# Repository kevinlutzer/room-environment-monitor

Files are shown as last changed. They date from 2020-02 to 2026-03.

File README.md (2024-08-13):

# Overview 

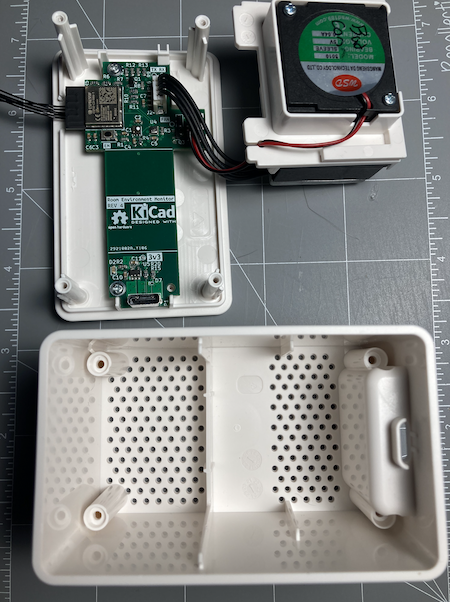
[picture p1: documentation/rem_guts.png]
REM Guts


The Room Environment Monitor (REM) project was something that I started back in 2017. I wanted a small IoT device that could tell me if there was a concerning amount of volatile organic compounds (VOCs) and CO2 in my workshop. I built the first version based on a Raspberry Pi Zero, CCS811 air quality monitor, and a BME280 humidity and temperature sensor.

I went through multiple iterations of the project with the overall objective to reduce cost while increasing the precision of the measurements being made. At that time, the CCS811 sensor cost about 40 dollars alone, which brought the V1 bill of materials (BOM) cost to about 70 CAD. Fast forward to 2023, Ikea released their [Vindriktning](https://www.ikea.com/ca/en/p/vindriktning-air-quality-sensor-60515911/) air quality monitor which uses a [PM1006K](https://en.gassensor.com.cn/Product_files/Specifications/LED%20Particle%20Sensor%20PM1006K%20Specification.pdf) sensor to measure 2.5um matter in the air. I designed my latest version of the Room Environment Monitor to replace the controller inside and make use of the device's case.

# Data Collection

The REM collects data from the following sensors:
1. [BME280](https://www.bosch-sensortec.com/products/environmental-sensors/humidity-sensors-bme280/) - Temperature, Humidity, Pressure
1. [SGP40-2.5k](https://sensirion.com/products/catalog/SGP40) - VOCs, C02  
1. [PM1006K](https://en.gassensor.com.cn/ParticulateMatterSensor/info_itemid_105.html) - particulate matter in the air (2.5ug/m^3, 1.0ug/m^3, 10ug/m^3)

This data is then pushed to a MQTT broker via the MQTT networking protocal. The broker then broadcasts the data to any subscribers. I use [n8n](https://n8n.io/) which is a workflow automation tool to subscribe to the REM data stream. n8n ensures that each piece of data in this stream is inserted as a new row in to a Postgres database. Bellow is a sequence diagram that shows how the data flows and is collected. 

<!-- https://sequencediagram.org/
title Room Environment Monitor Data Collection 

REM->MQTT Broker:publish data over tcp/ip using MQTT
MQTT Broker->n8n:broad cast data over tcp/ip using MQTT 
n8n->Postgres: insert new row  -->

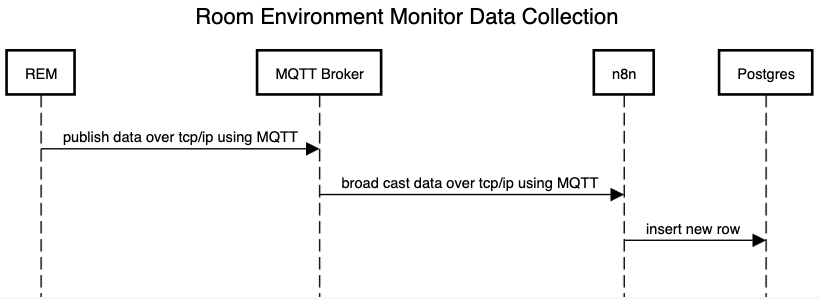
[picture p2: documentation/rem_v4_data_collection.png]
Data Collection Sequence Diagram


<!-- # Data Visualization -->

I use Grafana, a free an open source tool to visualize the collected data in my Postgres database. Here is a screenshot of the dashboard that I have created to visualize the data.

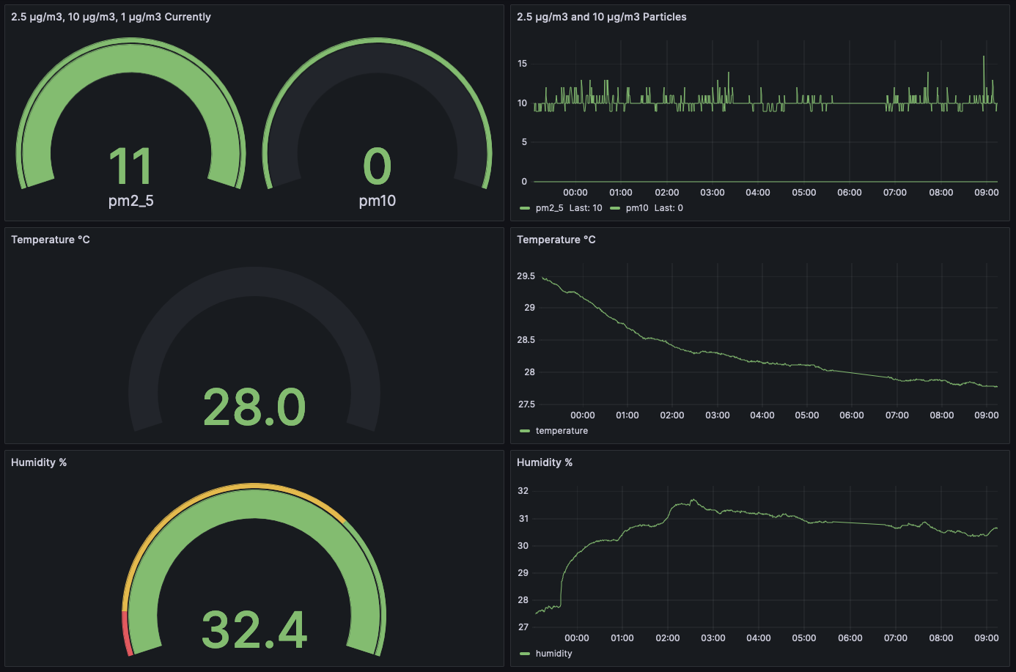
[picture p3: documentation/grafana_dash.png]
Data Visualization


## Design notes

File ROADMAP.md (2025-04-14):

# Roadmap 🗺️

1. Add the ability for the sample rate to be dynamically updated over mqtt.
1. Add TLS and user/password auth support.
1. Integrate the security chip. Right now the firmware does not use the onboard security chip (TPM) for hashing, password storage, etc.

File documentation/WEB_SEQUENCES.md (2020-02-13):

title Data Collection and Transmission Sequence (Raspberry PI)

Raspberry Pi->+Air Sensor: get air quality data
Air Sensor-->-Raspberry Pi: data
Raspberry Pi->+Temperature Sensor: get temperature and humidity
Temperature Sensor-->-Raspberry Pi: data
Raspberry Pi->+Google IOT Core: publishes data as message
Google IOT Core-->-Raspberry Pi: reciept for recieved message

title Data Store and Processing Sequence (Google Cloud Platform)

Google IOT Core->Google Pubsub: publish data from raspberry pi
Google Pubsub-->-Google IOT Core: success
Google Pubsub->+Google Function: recieve pub/sub message with data
Google Function->+Firestore: writes data to database
Firestore-->-Google Function: success
Google Function-->-Google Pubsub: sucess

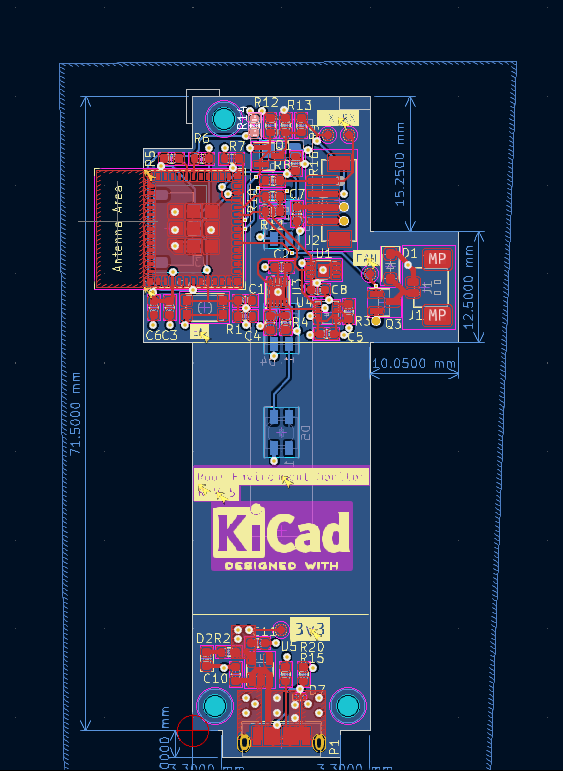
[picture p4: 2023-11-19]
documentation/v5-pcb 2/board_layout.png

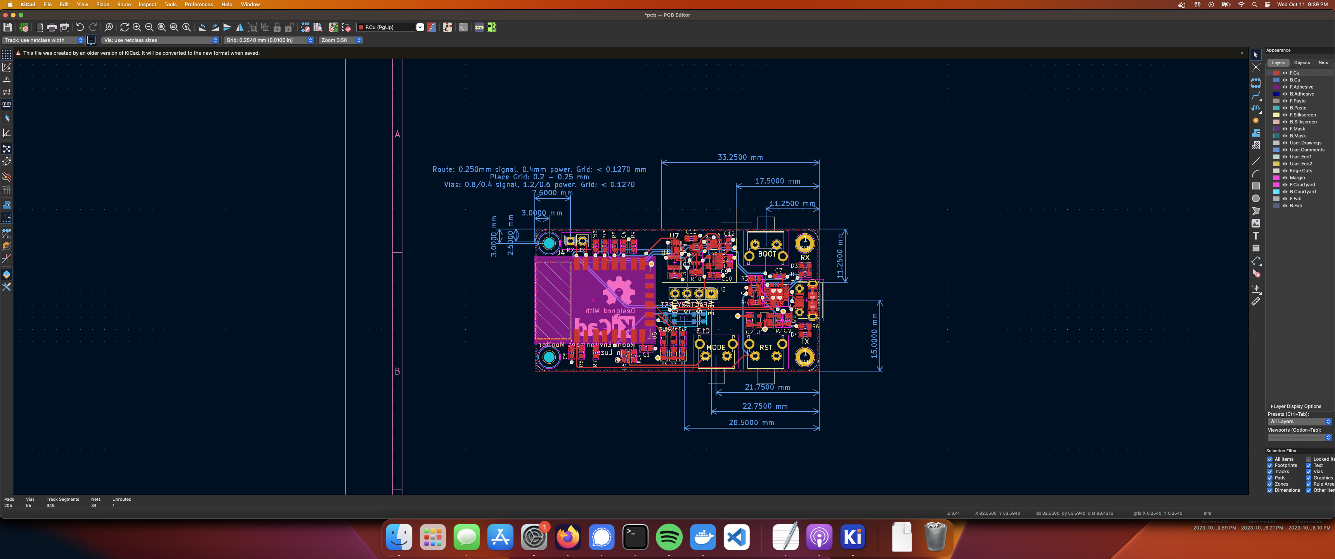
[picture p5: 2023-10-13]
documentation/v2/pcb.png

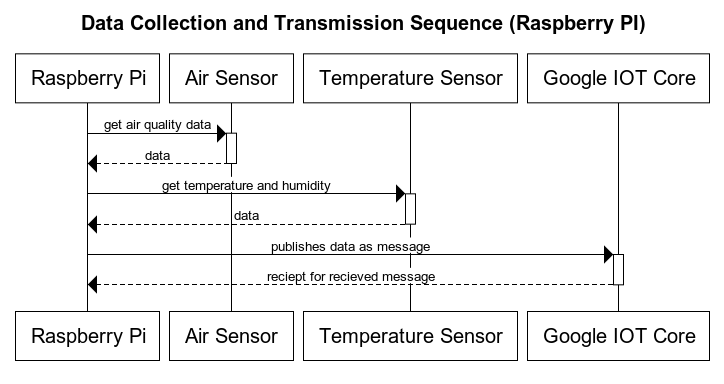
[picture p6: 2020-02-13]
documentation/data_collection_raspberry_pi_transmission_sequence_diagram.png

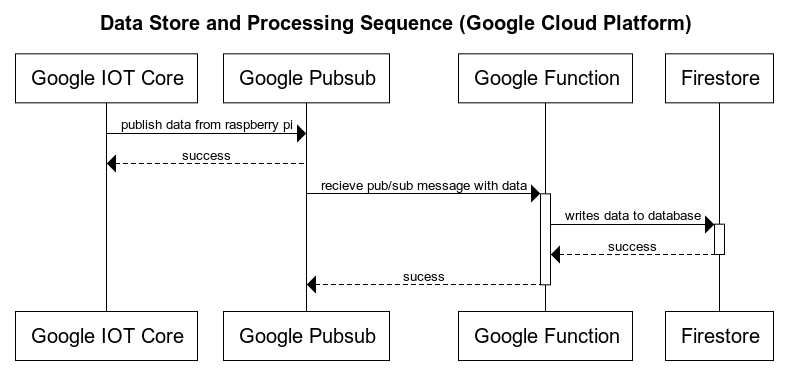
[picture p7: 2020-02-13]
documentation/data_store_and_processing_sequence_google_cloud_platform.png

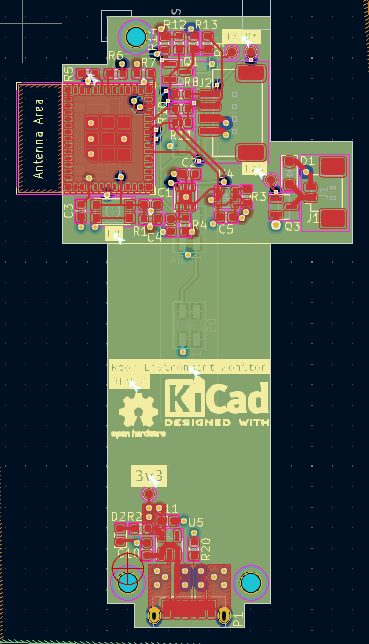
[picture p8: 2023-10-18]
documentation/v4-pcb/board_layout.png

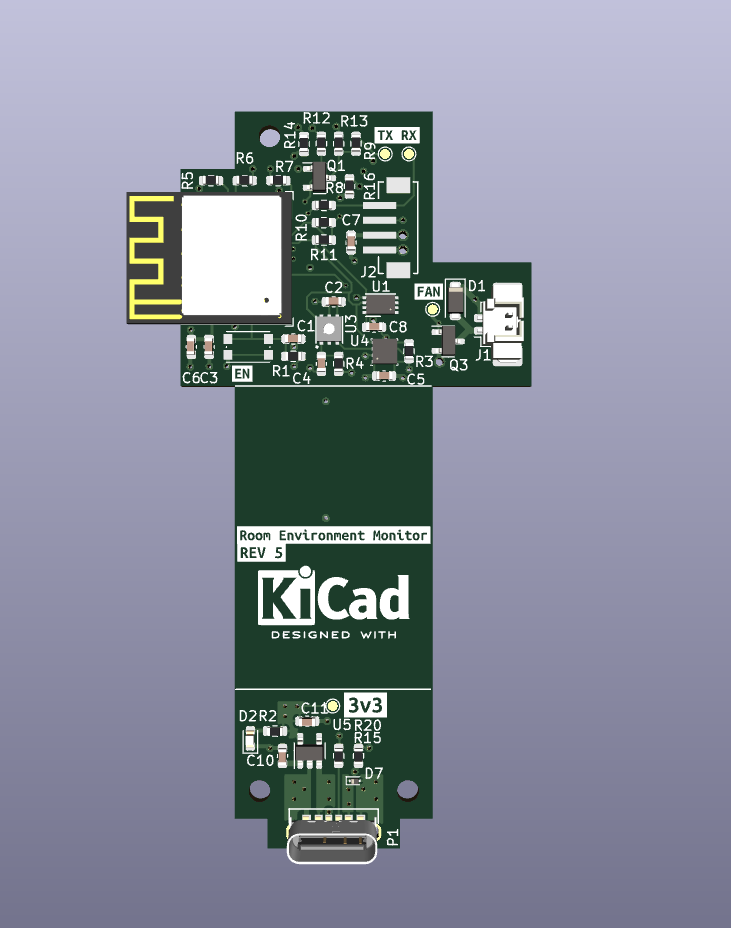
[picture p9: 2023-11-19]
documentation/v5-pcb 2/3d.png

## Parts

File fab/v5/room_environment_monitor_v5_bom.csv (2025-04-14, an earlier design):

Reference | Value | Datasheet | Footprint | Qty | DNP
C1,C2,C3,C4,C5,C8 | 0u1 | ~ | Capacitor_SMD:C_0603_1608Metric | 6 | C1590
C6,C7,C10,C11 | 1u | -- mixed values -- | Capacitor_SMD:C_0603_1608Metric | 4 | C1592
D1 | CDBMS160 | https://wmsc.DNP.com/wmsc/upload/file/pdf/v2/DNP/2312271638_Comchip-CDBMS160-HF_C7100383.pdf | Diode_SMD:D_SOD-123F | 1 | C7100383
D2 | LED | ~ | LED_SMD:LED_0603_1608Metric | 1 | C1590
D7 | ESD9X3 | https://www.onsemi.com/pdf/datasheet/esd9x3.3st5g-d.pdf | Diode_SMD:D_SOD-923 | 1 | C130456
J1 | Conn_01x02_Pin | ~ | Connector_Molex:Molex_PicoBlade_53398-0271_1x02-1MP_P1.25mm_Vertical | 1 | C122410
J2 | Conn_01x04_Pin | ~ | Kevin_Lutzer_Lbr:CONN_B4B-ZR-SM4-TF_JST | 1 | C265083
Q1,Q3 | BSS138 | -- mixed values -- | Package_TO_SOT_SMD:SOT-23 | 2 | C52895
R1,R3,R7,R12,R13,R16 | 10k | ~ | Resistor_SMD:R_0603_1608Metric | 6 | C15401
R2 | 220 | ~ | Resistor_SMD:R_0603_1608Metric | 1 | C1226
R4 | 4.7 | ~ | Resistor_SMD:R_0603_1608Metric | 1 | C23162
R5,R6,R8,R9 | 0 | ~ | Resistor_SMD:R_0603_1608Metric | 4 | C15402
R10,R11 | 2k2 | ~ | Resistor_SMD:R_0603_1608Metric | 2 | C4190
R15,R20 | 5.1k | ~ | Resistor_SMD:R_0603_1608Metric | 2 | C14677
SW1 | SW_SPST | ~ | Button_Switch_SMD:SW_Push_1P1T_NO_CK_KMR2 | 1 | C72443
U2 | ESP32-C3-MINI-1 | https://www.espressif.com/sites/default/files/documentation/esp32-c3-mini-1_datasheet_en.pdf | PCM_Espressif:ESP32-C3-MINI-1 | 1 | C2838502
U3 | SGP30-2.5K | https://mm.digikey.com/Volume0/opasdata/d220001/medias/docus/2578/SGP30%20Datasheet.pdf | Kevin_Lutzer_Lbr:SGP30-2.5K_SEN | 1 | C2874215
U4 | BME280 | https://www.bosch-sensortec.com/media/boschsensortec/downloads/datasheets/bst-bme280-ds002.pdf | Package_LGA:Bosch_LGA-8_2.5x2.5mm_P0.65mm_ClockwisePinNumbering | 1 | C92489
U5 | AP2112K-3.3 | https://www.diodes.com/assets/Datasheets/AP2112.pdf | Package_TO_SOT_SMD:SOT-23-5 | 1 | C51118

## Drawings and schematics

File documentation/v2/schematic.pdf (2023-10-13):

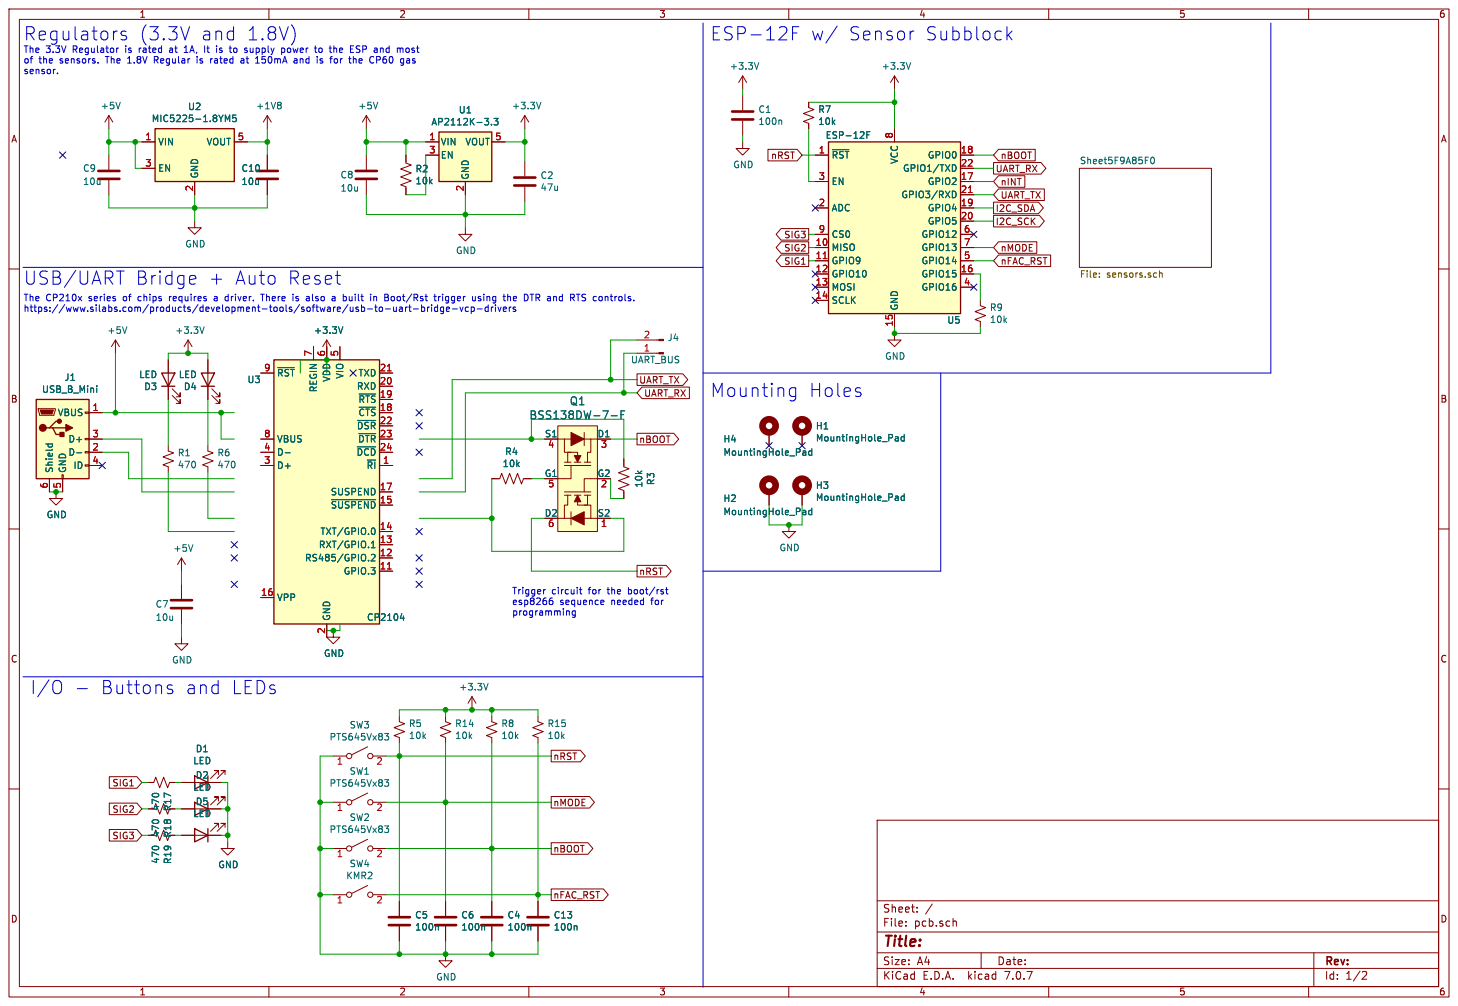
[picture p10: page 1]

USB/UART Bridge + Auto Reset

ID 4 GND 5 Shield 6 GND

Id: 1/2 Title: File: pcb.sch Sheet: /

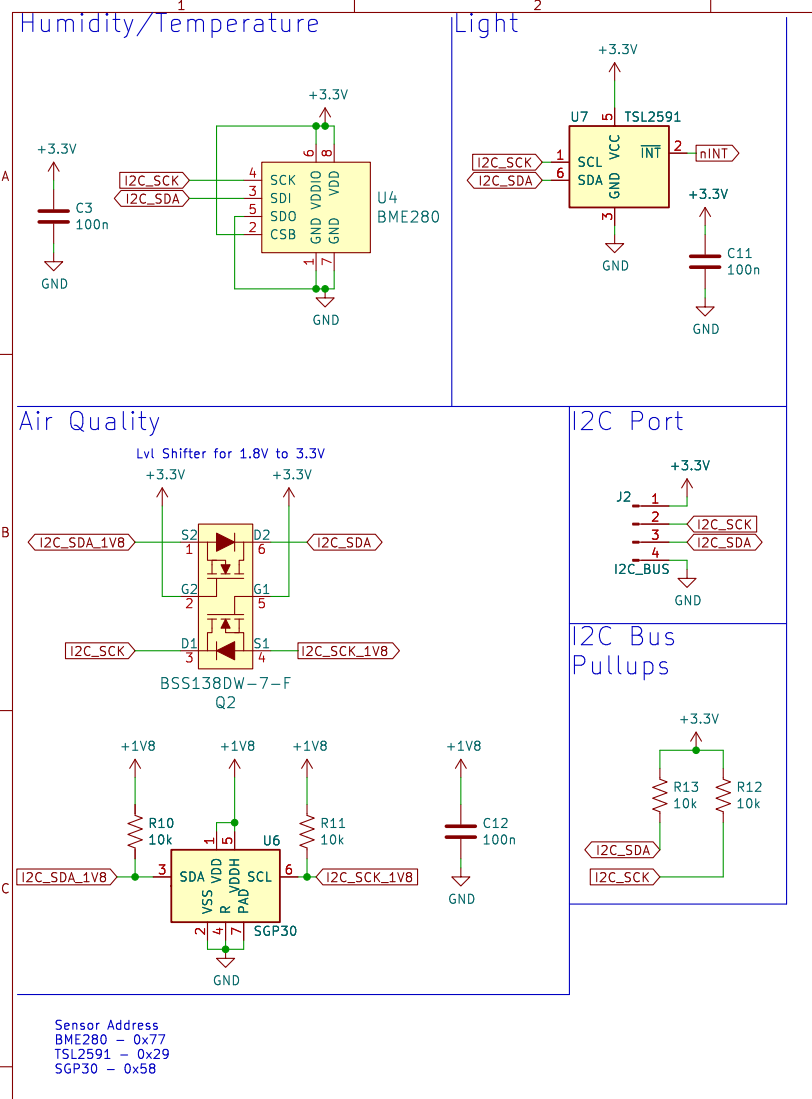
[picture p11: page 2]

I2C Port Sensor Address BME280 - 0x77 TSL2591 - 0x29 SGP30 - 0x58 Humidity/Temperature

1 CSB 2 SDI 3 SCK 4 SDO 5 VDDIO

File: sensors.sch Sheet: /Sheet5F9A85F0/
Id: 2/2 Title: Sensors

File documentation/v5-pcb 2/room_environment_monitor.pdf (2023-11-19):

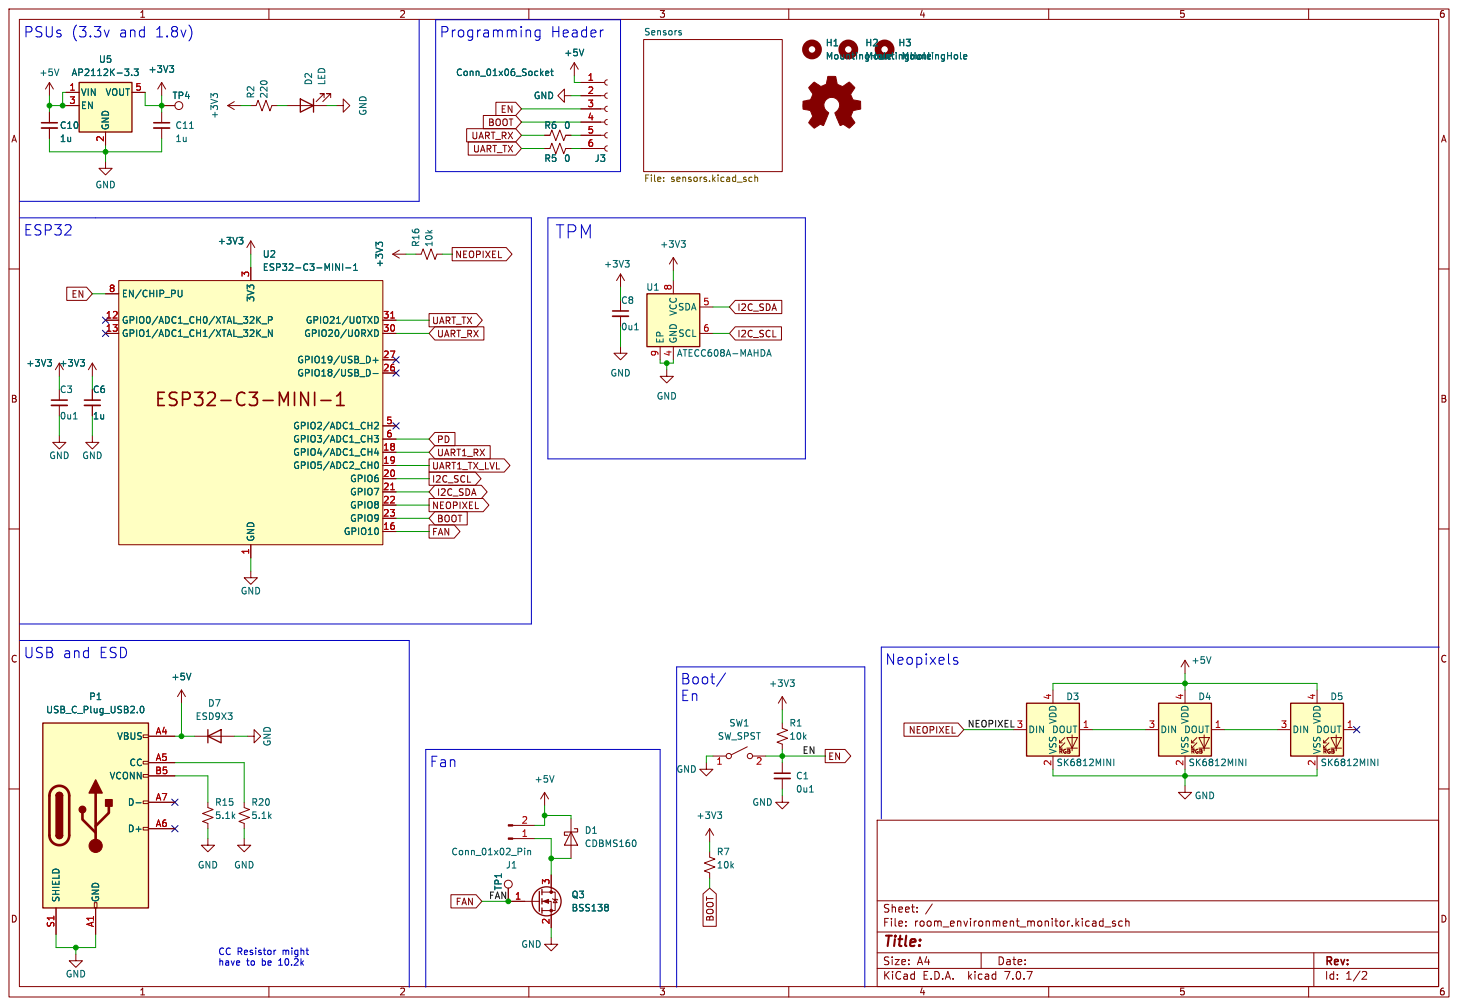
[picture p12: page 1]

2 EN 3 VOUT 5 U5 AP2112K-3.3 GND A1 VBUS A4 CC A5 D+ A6 D- A7 VCONN B5 SHIELD S1 P1 USB_C_Plug_USB2.0

2 EN 3 VOUT 5 +3V3 TP4 U2ESP32-C3-MINI-1 GND

Neopixels USB and ESD

Id: 1/2 Title: File: room_environment_monitor.kicad_sch Sheet: /

CC Resistor might have to be 10.2k

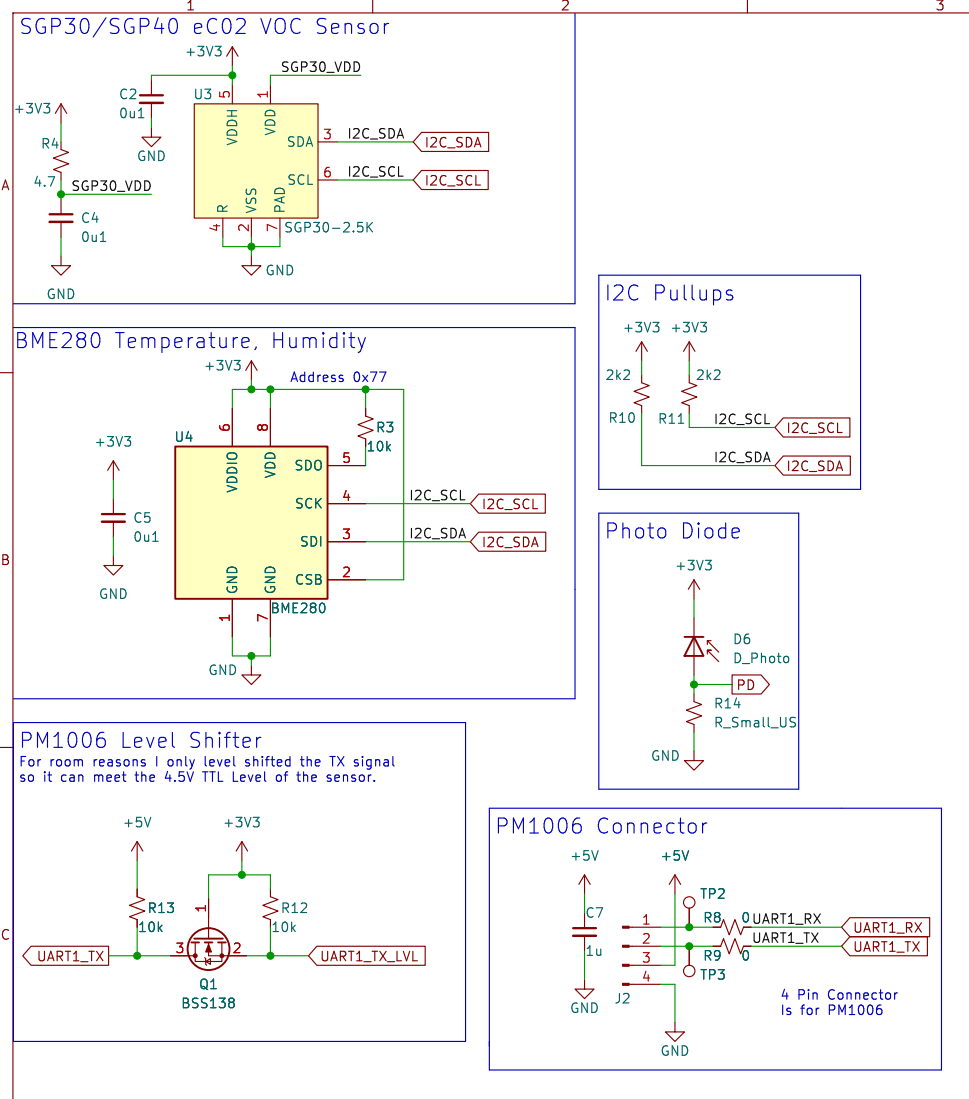
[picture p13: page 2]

1 CSB 2 SDI 3 SCK 4 SDO 5 VDDIO

Id: 2/2 Title: File: sensors.kicad_sch Sheet: /Sensors/

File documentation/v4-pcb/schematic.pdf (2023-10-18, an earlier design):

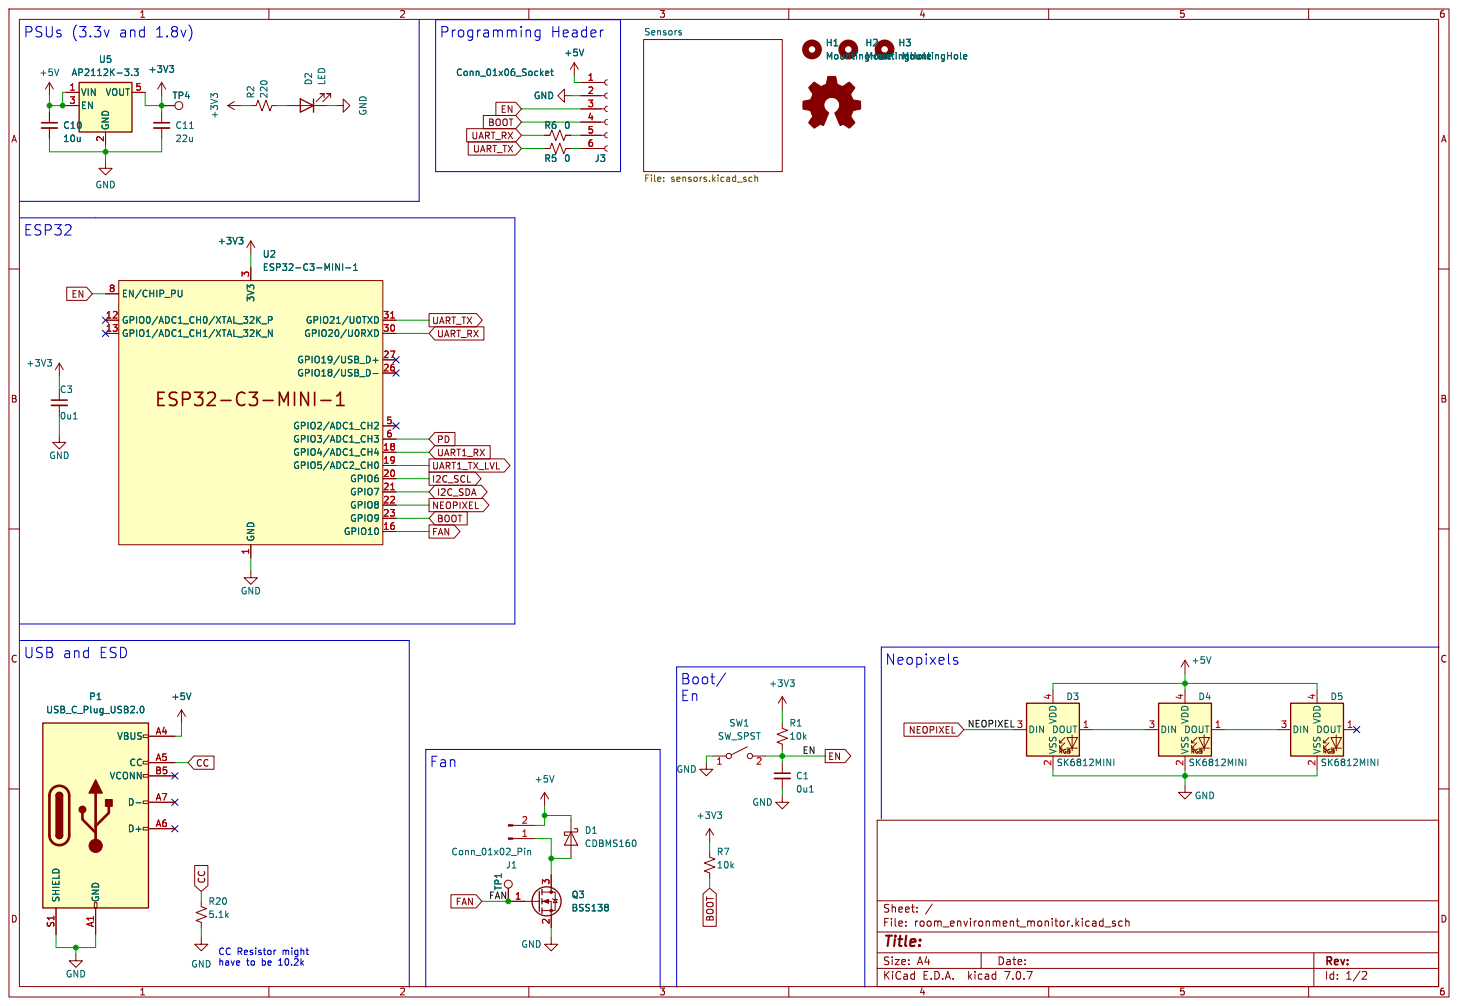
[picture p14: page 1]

2 3TP1 P1 +5V USB_C_Plug_USB2.0 GND A1 VBUS A4 CC A5 D+ A6 D- A7 VCONN B5 SHIELD S1 U2ESP32-C3-MINI-1 GND

CC Resistor might have to be 10.2k USB and ESD

2 3 Q3 BSS138 GND A1 VBUS A4 CC A5 D+ A6 D- A7 VCONN B5 SHIELD S1 P1 USB_C_Plug_USB2.0 GND

Id: 1/2 Title: File: room_environment_monitor.kicad_sch Sheet: /

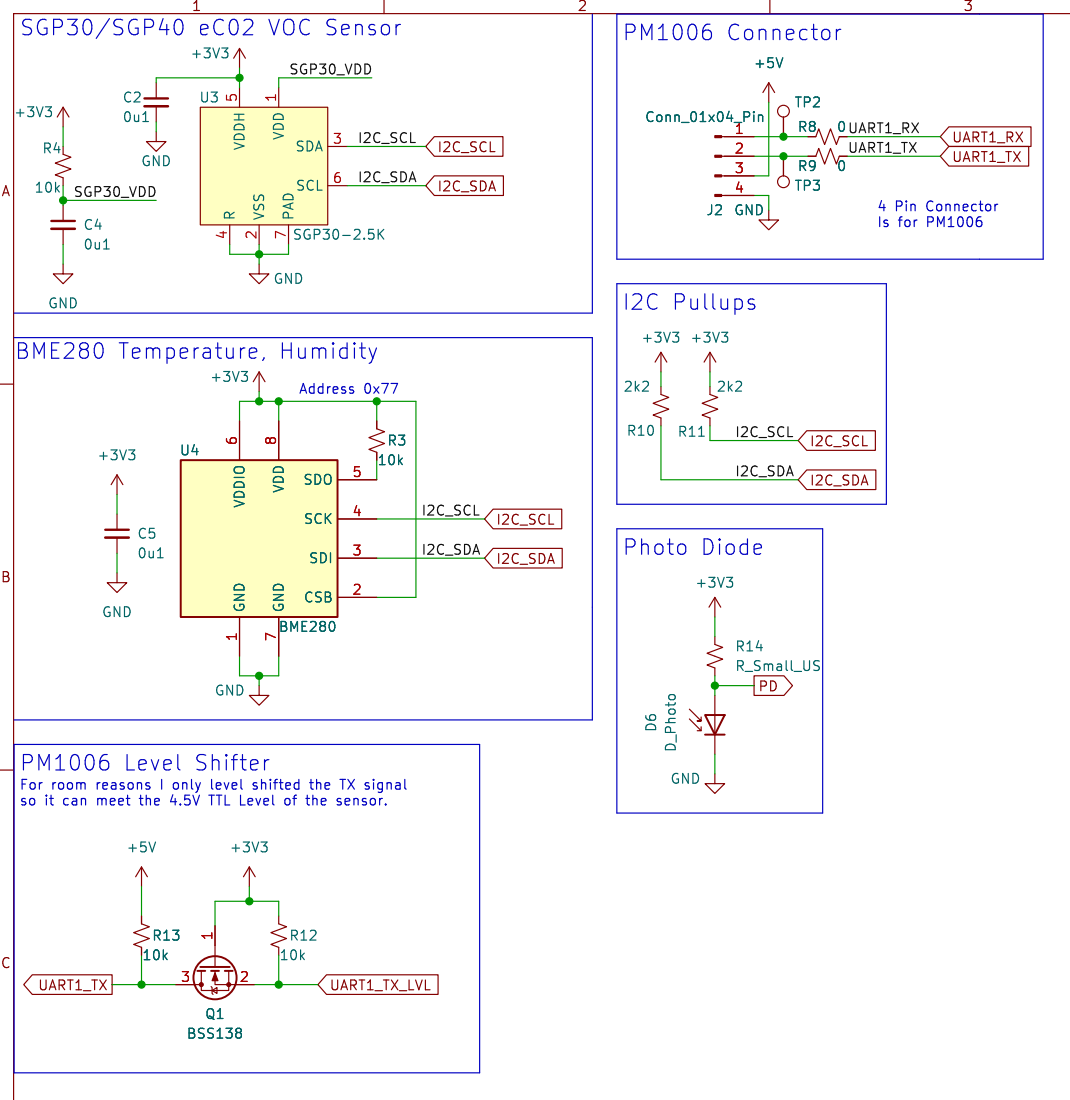
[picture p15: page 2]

1 CSB 2 SDI 3 SCK 4 SDO 5 VDDIO

PM1006 Level Shifter
For room reasons I only level shifted the TX signal so it can meet the 4.5V TTL Level of the sensor.

Id: 2/2 Title: File: sensors.kicad_sch Sheet: /Sensors/

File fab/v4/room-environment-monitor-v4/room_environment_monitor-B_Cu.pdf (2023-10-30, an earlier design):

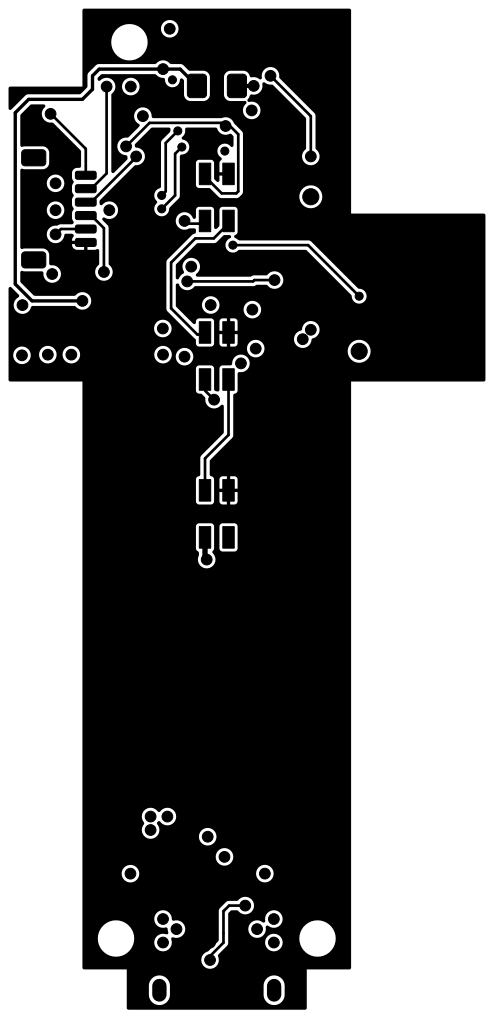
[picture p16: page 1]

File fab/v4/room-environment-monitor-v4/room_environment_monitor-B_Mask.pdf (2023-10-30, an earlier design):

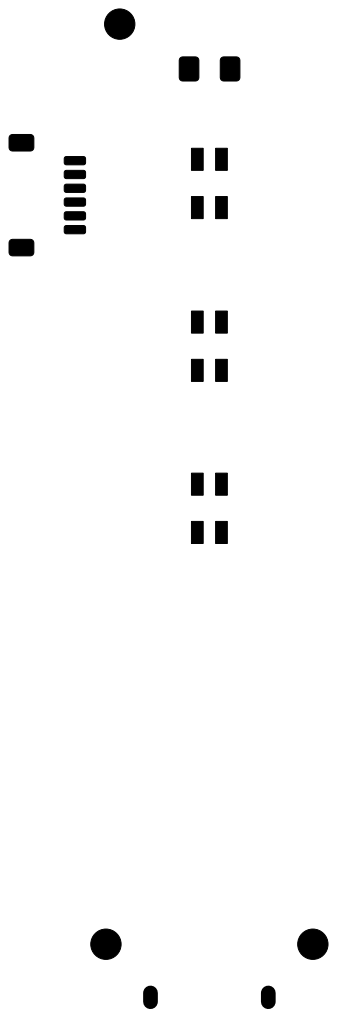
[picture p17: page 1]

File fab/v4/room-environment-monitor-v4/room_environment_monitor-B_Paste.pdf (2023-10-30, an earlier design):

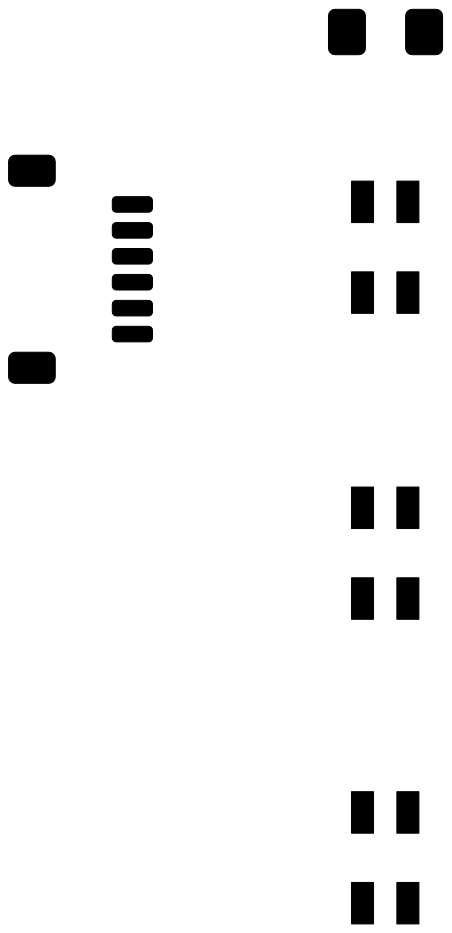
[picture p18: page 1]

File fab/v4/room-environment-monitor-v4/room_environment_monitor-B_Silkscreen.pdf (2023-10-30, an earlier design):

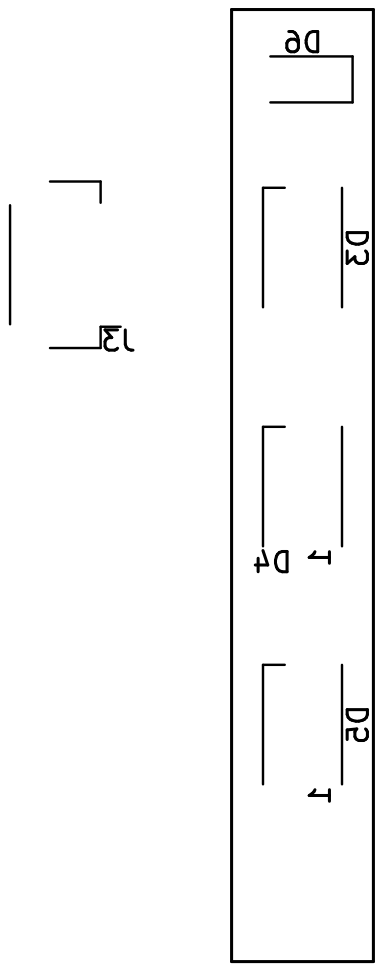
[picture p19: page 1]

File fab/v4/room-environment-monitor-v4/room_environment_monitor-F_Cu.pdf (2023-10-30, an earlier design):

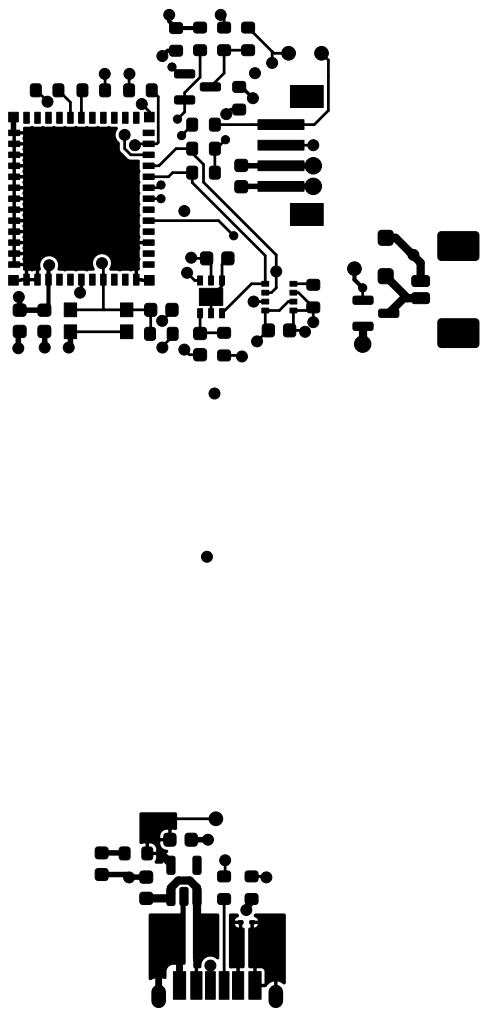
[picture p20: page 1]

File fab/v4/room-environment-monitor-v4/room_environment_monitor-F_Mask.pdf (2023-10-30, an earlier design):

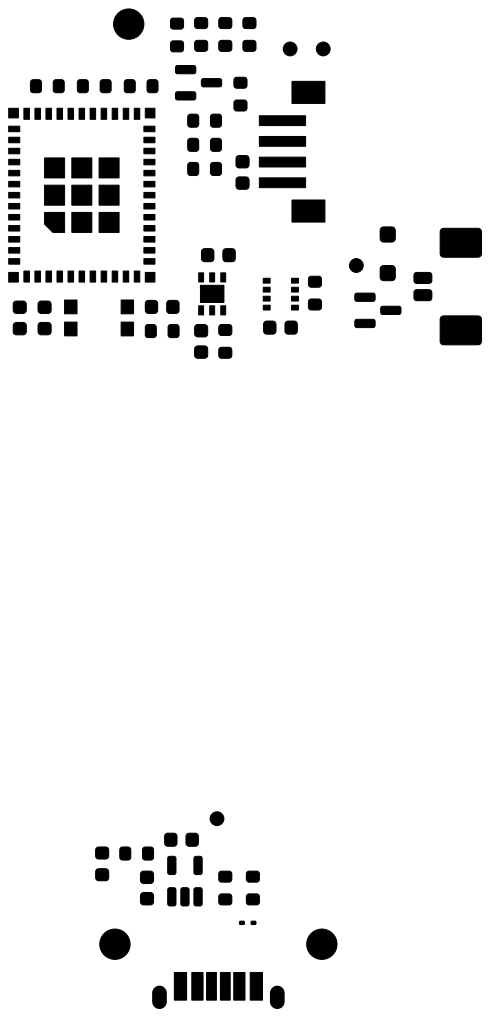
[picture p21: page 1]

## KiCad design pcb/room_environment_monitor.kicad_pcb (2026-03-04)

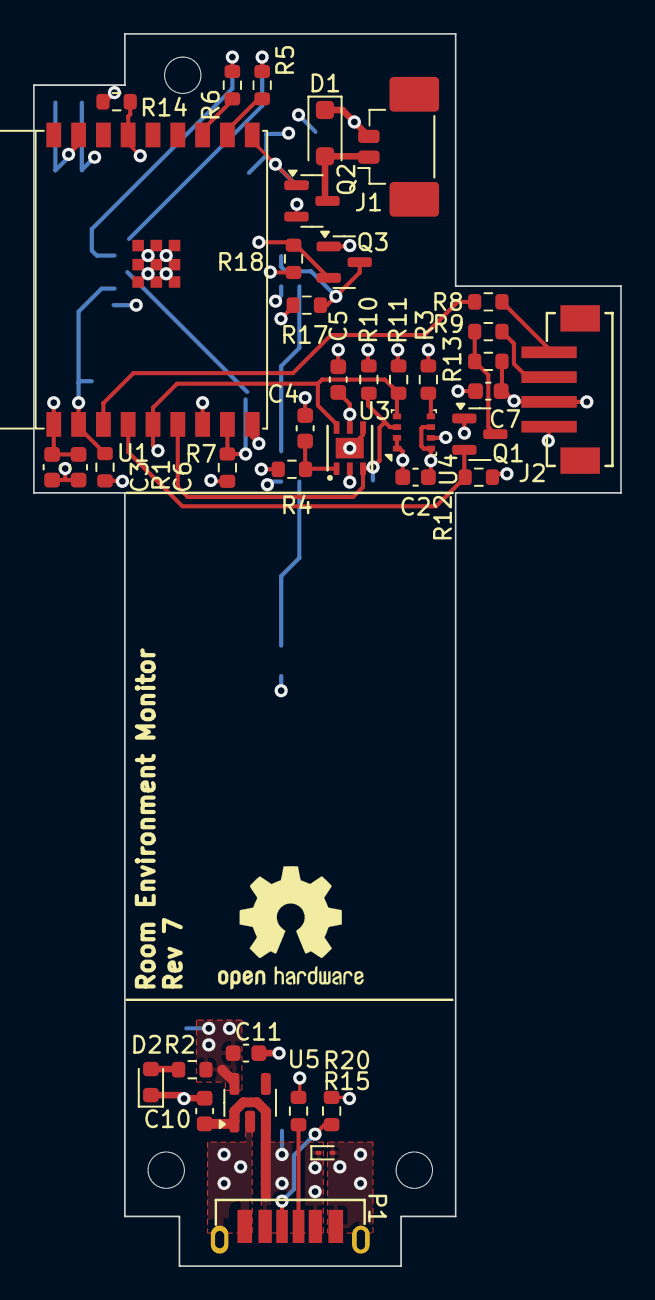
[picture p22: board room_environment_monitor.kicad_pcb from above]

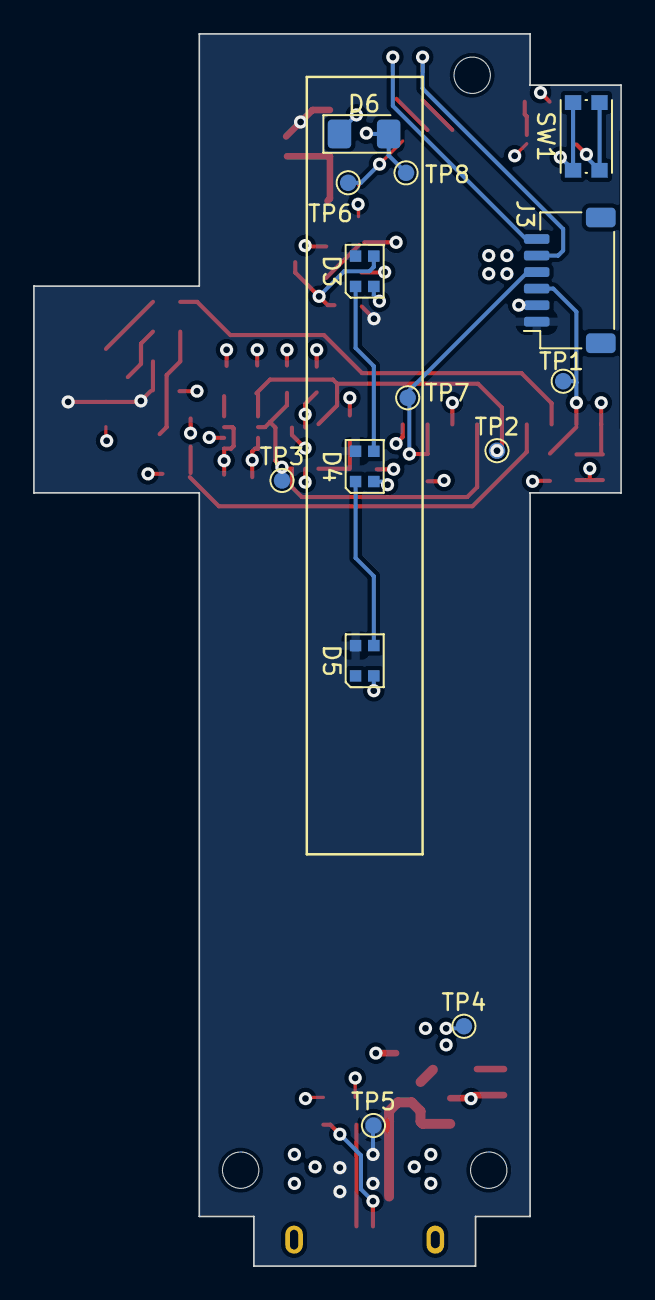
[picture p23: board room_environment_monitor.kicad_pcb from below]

Board: 4 copper layers, 35.5 x 74.5 mm, 56 parts (14 on the bottom side), 29 nets.

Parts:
C2, C3, C4, C5: 0u1; C_0603_1608Metric
C6, C7, C10, C11: 1u; C_0603_1608Metric
D1: CDBMS160; D_SOD-123F
D2: LED; LED_0603_1608Metric
D3, D4, D5: WS2812B-2020; LED_WS2812B-2020_PLCC4_2.0x2.0mm
D6: D_Photo; D_1206_3216Metric_Pad1.42x1.75mm_HandSolder
D7: ESD9X3; D_SOD-923
H1, H2, H3: MountingHole; MountingHole_2.2mm_M2_DIN965
J1: Conn_01x02_Pin; Molex_PicoBlade_53398-0271_1x02-1MP_P1.25mm_Vertical
J2: Conn_01x04_Pin; CONN_B4B-ZR-SM4-TF_JST
J3: Conn_01x06_Socket; JST_SH_SM06B-SRSS-TB_1x06-1MP_P1.00mm_Horizontal
P1: USB_C_Plug_USB2.0; CONN6_USB4130-GF-C_GCT
Q1, Q2, Q3: BSS138; SOT-23
R1, R3, R7, R12, R13, R17, R18: 10k; R_0603_1608Metric
R2: 220; R_0603_1608Metric
R4: 4.7; R_0603_1608Metric
R5, R6, R8, R9: 0; R_0603_1608Metric
R10, R11: 2k2; R_0603_1608Metric
R14: 10M; R_0603_1608Metric
R15, R20: 5.1k; R_0603_1608Metric
SW1: SW_SPST; SW_Push_1P1T_NO_CK_KMR2
TP1, TP2, TP3, TP4, TP5, TP6, TP7, TP8: TestPoint; TestPoint_Pad_D1.0mm
U1: ESP32-C3-WROOM-02
U3: SGP40; SGP30-2.5K_SEN-M
U4: BME280; Bosch_LGA-8_2.5x2.5mm_P0.65mm_ClockwisePinNumbering
U5: AP2112K-3.3; SOT-23-5

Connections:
+3V3: C2.1, C3.1, C5.1, C6.1, C11.1, D6.1 (K), Q1.1 (G), Q3.1 (G), R1.1, R2.1, R3.1, R4.1, R7.1, R10.2, R11.2, R12.1, R18.1, TP4.1, U1.1 (3V3), U3.5 (VDDH), U4.6 (VDDIO), U4.8 (VDD), U5.5 (VOUT)
+5V: C7.1, C10.1, D1.1 (K), D3.4 (VDD), D4.4 (VDD), D5.4 (VDD), D7.1 (K), J1.2, J2.3, J3.1, P1.A9 (VBUS), P1.B9 (VBUS), R13.1, R17.1, TP5.1, U5.1 (VIN), U5.3 (EN)
/NEOPIXEL_LVL: D3.3 (DIN), Q3.3 (D), R17.2
/Sensors/SGP30_VDD: C4.1, R4.2, U3.1 (VDD)
BOOT: J3.4, R7.2, TP7.1, U1.8 (GPIO9)
EN: J3.3, R1.2, TP1.1, U1.2 (EN/CHIP_PU)
FACT_REST: SW1.2 (B), U1.17 (GPIO1/ADC1_CH1/XTAL_32K_N)
FAN: Q2.1 (G), TP6.1, U1.10 (GPIO10)
GND: C2.2, C3.2, C4.2, C5.2, C6.2, C7.2, C10.2, C11.2, D2.1 (K), D3.2 (VSS), D4.2 (VSS), D5.2 (VSS), D7.2 (A), J2.4, J3.2, P1.A12 (GND), P1.B12 (GND), P1.S1 (SHIELD), Q2.2 (S), R14.1, R15.2, R20.2, SW1.1 (A), U1.9 (GND), U1.19 (GND), U3.2 (VSS), U3.4 (N/A), U3.7 (PAD), U4.1 (GND), U4.2 (CSB), U4.7 (GND), U5.2 (GND)
I2C_SCL: R11.1, TP2.1, U1.5 (GPIO6), U3.6 (SCL), U4.4 (SCK)
I2C_SDA: R10.1, TP3.1, U1.6 (GPIO7), U3.3 (SDA), U4.3 (SDI)
NEOPIXEL: Q3.2 (S), R18.2, U1.7 (GPIO8)
unnamed: D1.2 (A), J1.1, Q2.3 (D)
unnamed: D2.2 (A), R2.2
unnamed: D3.1 (DOUT), D4.3 (DIN)
unnamed: D4.1 (DOUT), D5.3 (DIN)
unnamed: J2.1, R8.1
unnamed: J2.2, R9.1
unnamed: J3.5, R6.2
unnamed: J3.6, R5.2
unnamed: P1.A5 (CC), R20.1
unnamed: P1.B5 (VCONN), R15.1
unnamed: R3.2, U4.5 (SDO)
PD: D6.2 (A), R14.2, TP8.1, U1.15 (GPIO3/ADC1_CH3)
UART1_RX: R8.2, U1.3 (GPIO4/ADC1_CH4)
UART1_TX: Q1.3 (D), R9.2, R13.2
UART1_TX_LVL: Q1.2 (S), R12.2, U1.4 (GPIO5/ADC2_CH0)
UART_RX: R6.1, U1.12 (GPIO21/U0TXD)
UART_TX: R5.1, U1.11 (GPIO20/U0RXD)

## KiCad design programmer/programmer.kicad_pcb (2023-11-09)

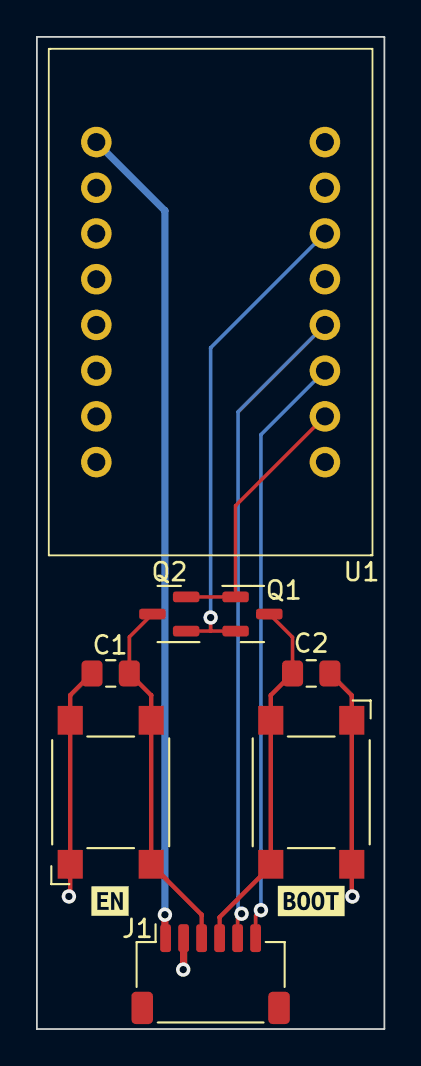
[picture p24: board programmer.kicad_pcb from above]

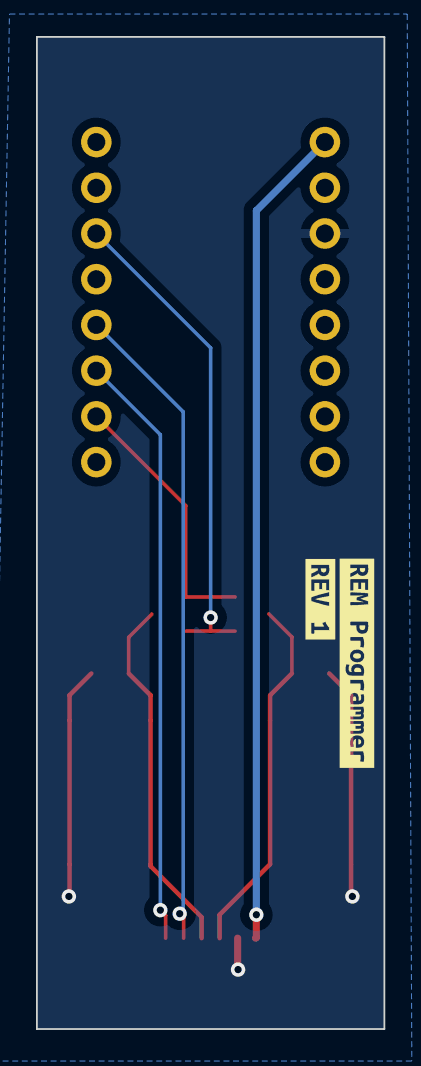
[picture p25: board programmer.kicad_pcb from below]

Board: 2 copper layers, 19.3 x 55.1 mm, 12 parts (2 on the bottom side), 8 nets.

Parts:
C1, C2: C; C_0805_2012Metric_Pad1.18x1.45mm_HandSolder
J1: Conn_01x06_Socket; JST_SH_SM06B-SRSS-TB_1x06-1MP_P1.00mm_Horizontal
Q1, Q2: BSS138; SOT-23
SW1, SW3: SW_Omron_B3FS; SW_SPST_Omron_B3FS-100xP
U1: Adafruit CP210XN Friend; Adafruit_CP210XN_Friend
kibuzzard-654D0F9E: G***; kibuzzard-654D0F9E
kibuzzard-654D0FC0: G***; kibuzzard-654D0FC0
kibuzzard-654D0FE8: G***; kibuzzard-654D0FE8
kibuzzard-654D1020: G***; kibuzzard-654D1020

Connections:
+5V: J1.1, U1.1 (VBUS)
BOOT: C2.1, J1.4, Q1.3 (D), SW3.2
DTR: Q1.2 (S), Q2.1 (G), U1.14 (DTR)
EN: C1.1, J1.3, Q2.3 (D), SW1.2
GND: C1.2, C2.2, J1.2, SW1.1, SW3.1, U1.3 (GND)
RTS: Q1.1 (G), Q2.2 (S), U1.10 (RTS)
UART_RX: J1.5, U1.12 (TXD)
UART_TX: J1.6, U1.11 (RXD)

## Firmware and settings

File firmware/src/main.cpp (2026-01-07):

#include "stdlib.h"

#include "Adafruit_BME280.h"
#include "Adafruit_NeoPixel.h"
#include "Adafruit_SGP40.h"
#include "EEPROM.h"
#include "PM1006K.h"
#include "PubSubClient.h"
#include "UUID.h"
#include "WiFi.h"
#include "Wire.h"

#include "mqtt_msg.hpp"
#include "pin_config.hpp"
#include "sensor_adapter.hpp"
#include "settings_manager.hpp"
#include "tasks.hpp"
#include "terminal.hpp"
#include "wifi_controller.hpp"

#define INIT_DEBUG false

#define PUBLISH_DATA_STACK 2048
#define PUBLISH_STATUS_STACK 4096
#define PUBLISH_TERMINAL_STACK 4096

#define SAMPLE_RATE 5000

// Statically create pointers to all of the providers.
// These instances should last the lifetime of the program
SensorAdapter *sensorAdapter;
SettingsManager *settingsManager;
PM1006K *pm1006k;
Adafruit_BME280 *bme280;
Adafruit_SGP40 *sgp40;
Adafruit_NeoPixel *neoPixel;
WiFiClient espClient;
Terminal *terminal;
PubSubClient *pubSubClient;
REMTaskProviders *providers;
LEDController *ledController;
UUID *uuidGenerator;

static BaseType_t prvRebootCommand(char *pcWriteBuffer, size_t xWriteBufferLen,
                                   const char *pcCommandString);

static const CLI_Command_Definition_t xRebootCommand = {
    "reboot", "\r\nreboot:\r\n this command reboots the esp32\r\n",
    prvRebootCommand, 0};

static BaseType_t prvUpdateSettingCommand(char *pcWriteBuffer,
                                          size_t xWriteBufferLen,
                                          const char *pcCommandString);

static const CLI_Command_Definition_t xUpdateSettingCommand = {
    "update-setting",
    "\r\nupdate-setting <NAME> <VALUE>:\r\n This command reboots the esp32. "
    "Valid settings include `ssid` and `password`\r\n",
    prvUpdateSettingCommand, 2};

static BaseType_t prvPrintSettingsCommand(char *pcWriteBuffer,
                                          size_t xWriteBufferLen,
                                          const char *pcCommandString);

static const CLI_Command_Definition_t xPrintSettingsCommand = {
    "print-settings",
    "\r\nprint-settings: \r\n This command will return a list of all of the "
    "settings and their values. \r\n",
    prvPrintSettingsCommand, 0};

static BaseType_t prvDebugCommand(char *pcWriteBuffer, size_t xWriteBufferLen,
                                  const char *pcCommandString);

static const CLI_Command_Definition_t xDebugCommand = {
    "debug", "\r\ndebug: \r\n This toggles the debug logging\r\n",
    prvDebugCommand, 0};

static BaseType_t prvWiFiStatusCommand(char *pcWriteBuffer,
                                       size_t xWriteBufferLen,
                                       const char *pcCommandString);

static const CLI_Command_Definition_t xWiFIStatusCommand = {
    "wifi-status",
    "\r\nwifi-status: \r\n Returns the wifi connected status\r\n",
    prvWiFiStatusCommand, 0};

static BaseType_t prvPrintSensorDataCommand(char *pcWriteBuffer,
                                            size_t xWriteBufferLen,
                                            const char *pcCommandString);

static const CLI_Command_Definition_t xPrintSensorDataCommand = {
    "print-sensor-data",
    "\r\nprint-sensor-data: \r\n Prints a snapshot of the sensor data.\r\n",
    prvPrintSensorDataCommand, 0};

/**
 * Setup the wifi connection and the NTP server. If the clock is not synced
 * with the NTP server, the function will return false
 */
void setupWiFi() {
  WiFiController *wifiController =
      new WiFiController(&WiFi, terminal, settingsManager);
  if (!wifiController->setupWiFi()) {
    terminal->debugln("Wifi Setup Failed");
  }

  wifiController->setupSNTP();
  if (!wifiController->verifyClockSync()) {
    terminal->debugln("Failed to sync the clock with the NTP server");
  }

  // Controller isn't needed again execpt for initial networking config
  delete wifiController;
}

/**
 * Setup the terminal and the terminal task that will handle the input and
 * output
 */
void setupTerminal() {

  Serial.begin(115200);
  terminal = new Terminal(INIT_DEBUG, &Serial);

  // Setup the terminal task that handles the input and output of the terminal
  xTaskCreate(TerminalTask, "Terminal Task", PUBLISH_TERMINAL_STACK, terminal,
              1, NULL);

  // Setup CLI Commands that can be run as soon as the terminal task is started
  FreeRTOS_CLIRegisterCommand(&xRebootCommand);
  FreeRTOS_CLIRegisterCommand(&xDebugCommand);
}

/**
 * Initializes the pubsub client which internally creates a MQTT connection to
 * the server. The server connected too is determeind by the mqtt server
 * setting.
 */
void setupPubSubClient() {
  pubSubClient = new PubSubClient(espClient);
  pubSubClient->setServer(settingsManager->getSetting(MQTT_SERVER_ID), 1883);
  pubSubClient->connect("arduinoClient");

  while (!pubSubClient->connected()) {
    terminal->debugln("Failed to connect to MQTT server, retrying...");
    pubSubClient->connect("arduinoClient");
    delay(1000);
  }
}

void setup() {

  Adafruit_NeoPixel NeoPixel(3, NEOPIXEL_PIN, NEO_GRB + NEO_KHZ800);
  NeoPixel.clear(); // set all pixel colors to 'off'. It only takes effect if
                    // pixels.show() is called

  // turn pixels to green one-by-one with delay between each pixel
  for (int pixel = 0; pixel < 3; pixel++) { // for each pixel
    NeoPixel.setPixelColor(
        pixel,
        NeoPixel.Color(0, 255,
                       0)); // it only takes effect if pixels.show() is called
    NeoPixel.show();        // update to the NeoPixel Led Strip

    delay(500); // 500ms pause between each pixel
  }

  // Turn on Fan
  pinMode(FAN, OUTPUT);
  digitalWrite(FAN, HIGH);

  setupTerminal();

  // Setup EEPROM
  int count = 0;
  while (count < 5 && !EEPROM.begin(EEPROM_SIZE)) {
    terminal->debugln("Failed to setup EEPROM, retrying...");
    count++;
    delay(1000);
  }

  // Setup settings manager and load settings from eeprom
  settingsManager = new SettingsManager(terminal, &EEPROM);
  if ((!settingsManager->loadSettings())) {
    terminal->debugln("Failed to load settings");
  }

  // Add tasks related to settings since settings manager is instantiated
  FreeRTOS_CLIRegisterCommand(&xUpdateSettingCommand);
  FreeRTOS_CLIRegisterCommand(&xPrintSettingsCommand);

  // Setup network utilities including the network connection,
  // sntp, and the mqtt client
  setupWiFi();
  setupPubSubClient();

  // Setup Controller and Controller Depedencies
  Serial1.begin(PM1006K::BAUD_RATE, SERIAL_8N1, PM1006K_RX_PIN, PM1006K_TX_PIN);
  pm1006k = new PM1006K(&Serial1);

  // Setup I2C
  Wire.begin(I2C_SDA, I2C_SCL);
  Wire.setClock(10000);

  // Setup BME280 Driver
  bme280 = new Adafruit_BME280();
  if (!bme280->begin(BME280_ADDRESS, &Wire)) {
    terminal->debugln("Failed to setup BME280");
  }

  // Setup the SGP40 Driver
  sgp40 = new Adafruit_SGP40();
  if (!sgp40->begin(&Wire)) {
    terminal->debugln("Failed to setup SGP40");
  }

  // Setup the neopixel controller and clear the pixels
  neoPixel =
      new Adafruit_NeoPixel(NUM_NEOPIXELS, NEOPIXEL_PIN, NEO_GRB + NEO_KHZ800);
  neoPixel->begin();
  neoPixel->clear();
  ledController = new LEDController(neoPixel, terminal);

  // Setup Controller
  sensorAdapter = new SensorAdapter(pm1006k, bme280, sgp40, terminal);

  // Create UUID Generator used for generating unique ids
  uuidGenerator = new UUID();
  uint32_t rn = esp_random();
  uuidGenerator->seed(rn);
  uuidGenerator->setRandomMode(); // This is important for the UUID to be unique
                                  // between reboots

  // Remainder of the commands that depend on providers instantiated above
  FreeRTOS_CLIRegisterCommand(&xWiFIStatusCommand);
  FreeRTOS_CLIRegisterCommand(&xPrintSensorDataCommand);

  // Setup the task providers and the task that publishes the messages
  providers = new REMTaskProviders(sensorAdapter, settingsManager, terminal,
                                   pubSubClient, uuidGenerator, ledController);

  xTaskCreate(PublishMQTTMsg, "Publish MQTT", PUBLISH_STATUS_STACK, providers,
              1, NULL);

  xTaskCreate(QueueDataTask, "Queue Data", PUBLISH_DATA_STACK, providers, 1,
              NULL);

  xTaskCreate(QueueStatusTask, "Status Data", PUBLISH_DATA_STACK, providers, 1,
              NULL);

  xTaskCreate(LEDUpdateTask, "LED Update Task", PUBLISH_DATA_STACK, providers,
              1, NULL);

#ifdef DEBUG_MEMORY_CHECK
  xTaskCreate(MemoryCheck, "Memory Check Task", PUBLISH_DATA_STACK, providers,
              1, NULL);

#endif

  terminal->debugln("Started tasks...");
}

// Main loop is uneeded because we are using freertos tasks to persist the
// application
void loop() { return; }

//
// Begin the CLI Command Definitions
//

BaseType_t prvRebootCommand(char *pcWriteBuffer, size_t xWriteBufferLen,
                            const char *pcCommandString) {
  ESP.restart();

  // Never reached because the esp32 reboots fully
  return pdTRUE;
}

BaseType_t prvUpdateSettingCommand(char *pcWriteBuffer, size_t xWriteBufferLen,
                                   const char *pcCommandString) {

  BaseType_t nameParamToStringLength, valueParamToStringLength;
  const char *nameParam =
      FreeRTOS_CLIGetParameter(pcCommandString, 1, &nameParamToStringLength);

  const char *valueParam =
      FreeRTOS_CLIGetParameter(pcCommandString, 2, &valueParamToStringLength);

  // Call the update function and validate the response note that if it is
  // false, it coul;d
  if (settingsManager->updateSetting(nameParam, valueParam,
                                     (int)valueParamToStringLength)) {
    snprintf(pcWriteBuffer, xWriteBufferLen, "Update setting successfully");
  } else {
    snprintf(pcWriteBuffer, xWriteBufferLen,
             "Failed to update setting check to make sure the setting name is "
             "valid and the length of the value is under %d characters",
             SETTING_LEN);
  }

  return pdFALSE;
}

BaseType_t prvDebugCommand(char *pcWriteBuffer, size_t xWriteBufferLen,
                           const char *pcCommandString) {

  bool debug_val = terminal->toggleDebug();
  snprintf(pcWriteBuffer, xWriteBufferLen, "Debug logging is now %s\r\n",
           debug_val ? "enabled" : "disabled");

  return pdFALSE;
}

BaseType_t prvPrintSettingsCommand(char *pcWriteBuffer, size_t xWriteBufferLen,
                                   const char *pcCommandString) {

  BaseType_t nameParamToStringLength, valueParamToStringLength;

  // If we get a false response from the print settings function, print an error
  // message It mostlikely is a memory allocation issue where xWriteBufferLen is
  // too small
  if (!settingsManager->printSettings(pcWriteBuffer, xWriteBufferLen)) {
    snprintf(pcWriteBuffer, xWriteBufferLen,
             "Failed to print the settings\r\n");
  }

  return pdFALSE;
}

BaseType_t prvWiFiStatusCommand(char *pcWriteBuffer, size_t xWriteBufferLen,
                                const char *pcCommandString) {

  // Grab the wifi information including the ip
  wl_status_t status = WiFi.status();
  String ip = WiFi.localIP().toString();

  if (!ip.length()) {
    snprintf(pcWriteBuffer, xWriteBufferLen,
             "WiFi status: %d \r\nIP: N/A \r\nWifi Status: N/A\r\n", status);
  } else {
    const char *ipCStr = ip.c_str();
    snprintf(pcWriteBuffer, xWriteBufferLen,
             "WiFi status: %d \r\nIP: %s\r\nWifi Status: %d\r\n", status,
             ipCStr, pubSubClient->connected());
  }

  return pdFALSE;
}

BaseType_t prvPrintSensorDataCommand(char *pcWriteBuffer,
                                     size_t xWriteBufferLen,
                                     const char *pcCommandString) {

  // If we have a mismatched config for the output buffer length this will
  // return false
  if (!sensorAdapter->printData(pcWriteBuffer, xWriteBufferLen)) {
    snprintf(pcWriteBuffer, xWriteBufferLen,
             "Failed to print the settings, write buffer passed is not long "
             "enough.\r\n");
  }

  return pdFALSE;
}

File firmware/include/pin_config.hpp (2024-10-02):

#ifndef _REM_PIN_CONFIG_HPP
#define _REM_PIN_CONFIG_HPP

#define PM1006K_RX_PIN 4
#define PM1006K_TX_PIN 5

#define FAN 10

#define I2C_SDA 7
#define I2C_SCL 6

#define NEOPIXEL_PIN 8
#define NUM_NEOPIXELS 3

#endif

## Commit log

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2018-05-19 add base sensor code
2018-05-20 update main code for python to take in arguments to collect sensor data
2018-05-24 update service and sensor stuff
2018-06-02 make main py actuall run sensor commands
2018-09-22 Bring in fan control
2018-10-02 refactor to add humidity and pressure sensoring
2018-10-23 refactor message for handling power status
2018-10-23 bring in new entity for device status
2018-10-23 add error handling for inital device status publishing
2019-02-01 write two tests and refactor the sensor service to not take in values
2019-12-25 switch to go mod
2020-02-05 build out the device model and update it in the pubsub handler
2020-02-05 get the device list api to work
2020-07-12 add pcb start with lipo battery charger
    [pcb.kicad_pcb, pcb.sch]
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2020-07-20 finish the shcematic design
    [pcb.kicad_pcb, pcb.sch]
2020-07-21 get the update done on the pcb design, finish it
    [pcb.kicad_pcb, pcb.sch]
2020-07-29 try update the node modules
    [pcb.kicad_pcb, pcb.sch]
2020-07-29 remove the switch, add some more logic
    [sensors.sch]
2020-07-29 update the pcb stuff
    [pcb.kicad_pcb, pcb.sch]
2020-07-30 finish laying out most of the pcb parts
    [pcb.kicad_pcb, pcb.sch, sensors.sch]
2020-07-31 finish the routing of the pcb all that is left is to clean up the silkscreen
    [pcb.kicad_pcb, pcb.sch, sensors.sch]
2020-08-07 add gerbers for room monitor v1
    [pcb-B_Cu.gbr, pcb-B_Mask.gbr, pcb-B_Paste.gbr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]
2020-08-08 make last minute changes
    [pcb-B_Cu.gbr, pcb-B_Mask.gbr, pcb-B_Paste.gbr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]
2020-08-17 Update the gerbers for the rem v1 and reroute the UART lines
    [pcb-B_Cu.gbr, pcb-B_Mask.gbr, pcb-B_Paste.gbr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]
2020-08-18 fix tsl2691 component
    [pcb-B_Cu.gbr, pcb-B_Mask.gbr, pcb-B_Paste.gbr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]
2020-08-20 cleanup sensors sheet
    [pcb-B_Cu.gbr, pcb-B_Mask.gbr, pcb-B_Paste.gbr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]
2020-08-20 add more comments to the pcb, cleanup board files
    [pcb.kicad_pcb, sensors.sch]
2020-09-01 update the footprint for the tsl2591
    [pcb.kicad_pcb, pcb.sch, sensors.sch]
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2021-01-08 switch i2c lines around
    [pcb.sch]
2021-01-09 use the right tsl2591 footprint
    [pcb.kicad_pcb, pcb.sch, sensors.sch]
2021-01-10 cleaning up logic
    [pcb.kicad_pcb, pcb.sch, sensors.sch]
2021-01-10 add zip file
    [pcb-B_Cu.gbr, pcb-B_Mask.gbr, pcb-B_Paste.gbr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]
2021-01-10 update gerbers
    [pcb-B_Cu.gbr, pcb-B_Mask.gbr, pcb-B_Paste.gbr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]
2023-10-12 add images of v2 schematic and pcb
2023-10-12 move gerbers
    [pcb-B_Cu.gbr, pcb-B_Mask.gbr, pcb-B_Paste.gbr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]
2023-10-13 bring in gitignore and v2 schematics
2023-10-13 move v2 gerbers
    [pcb-B_Cu.gbr, pcb-B_Mask.gbr, pcb-B_Paste.gbr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]
2023-10-15 get the schematic done, need to optomize for parts
    [room_environment_monitor.kicad_pcb, room_environment_monitor.kicad_sch]
2023-10-17 finish the routing need to move the esp32 up 5.5 mm
    [room_environment_monitor.kicad_pcb, room_environment_monitor.kicad_sch, sensors.kicad_sch]
2023-10-17 finish routing the PCB
    [room_environment_monitor.kicad_pcb, room_environment_monitor.kicad_sch, sensors.kicad_sch]
2023-10-18 finish v4 and the images for doucmentation
    [room_environment_monitor.kicad_pcb, room_environment_monitor.kicad_sch, sensors.kicad_sch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]
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2023-10-19 cleanup undeeded pdf files and add gerbers
    [room_environment_monitor-B_Cu.gbl, room_environment_monitor-B_Mask.gbs, room_environment_monitor-B_Paste.gbp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]
2023-10-30 update fab
    [room_environment_monitor.kicad_pcb, room_environment_monitor.kicad_sch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]
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2023-11-01 add the test and pm1006 base driver files
2023-11-06 add controller and base programming pcb
    [programmer.kicad_pcb, programmer.kicad_sch]
2023-11-09 add the built programmer pcb, gerbers and bom
    [programmer-B_Cu.gbl, programmer-B_Mask.gbs, programmer-B_Paste.gbp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]
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2023-11-09 switch the sda and scl lines on the SGP40
    [room_environment_monitor.kicad_pcb, sensors.kicad_sch]
2023-11-09 Use a 4.7 ohm resistor for the RC Filter on the VDD for SGP40
    [room_environment_monitor.kicad_pcb, sensors.kicad_sch]
2023-11-13 add the routing for hte PM1006K enable, and other fixes
    [room_environment_monitor.kicad_pcb, room_environment_monitor.kicad_sch, sensors.kicad_sch]
2023-11-18 update the pcb to include the updated schematic for the PD and the TPM moudle
    [room_environment_monitor.kicad_pcb, room_environment_monitor.kicad_sch, sensors.kicad_sch]
2023-11-19 add new gerbers and bom, fix DRC and ERC for pcb
    [room_environment_monitor-B_Cu.gbl, room_environment_monitor-B_Mask.gbs, room_environment_monitor-B_Paste.gbp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]
2024-08-10 add setup.sh, pcb and programmer files
2024-08-21 add the input/out via uart, tie everything to the terminal class, cleanup
2024-09-02 get print settings, debug toggling, and update settings working
2024-09-02 fix deivce id publishing for status
    [main.cpp]
2024-09-08 fix bug where I was using the ssid for the password when connecting to wifi on boot, cleanup printsize with a define
    [main.cpp]
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2024-09-16 fix fan pinoout, cleanup led usage
    [main.cpp, pin_config.hpp]
2024-11-07 swap where the settings cli commands get swappedY
    [main.cpp]
2024-11-16 fix the randomness of the uuid generation (#9)
    [main.cpp]
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2025-04-14 Kevinlutzer/upgrade to v8 (#11)
    * Add new plugins for BOM and PNP file management
    * make some more progress
    * merge in main
    * cleanup sensors
    * pass drc
    * move files
    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
    [BOM-room_environment_monitor.csv, bom.csv, designators.csv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]
2025-04-14 up the sample rates to something more reasonable for the release
2025-06-02 Fix Serialization Of Google Docs (#13)
    * fix serialize documents
    * bring back rssi
    * formatting
    [main.cpp]
2025-06-04 Fix Memory Leak With Printing Data (#14)
    * fix memory leak
    * bring back led
    * cleanup
    * reconnect
    * lint
    [main.cpp]
2025-08-03 do the reroute for the larger ESP32 module
    [room_environment_monitor.kicad_pcb, room_environment_monitor.kicad_sch, sensors.kicad_sch]
2025-08-04 cleanup files
    [room_environment_monitor.kicad_pcb, room_environment_monitor.kicad_sch]
2025-08-07 finish layout for factory reset
    [room_environment_monitor.kicad_pcb, room_environment_monitor.kicad_sch]
2025-08-07 add v6, remove all uneeded files
    [BOM-room_environment_monitor.csv, bom.csv, designators.csv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]
